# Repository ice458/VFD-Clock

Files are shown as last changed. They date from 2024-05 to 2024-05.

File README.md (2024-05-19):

# VFD-Clock
This is a project for a table clock using a VFD.  
For more information, please visit [this site.](https://ice458.wordpress.com/%e5%ae%9f%e7%94%a8%e7%9a%84%e3%81%aavfd%e6%99%82%e8%a8%88/)  
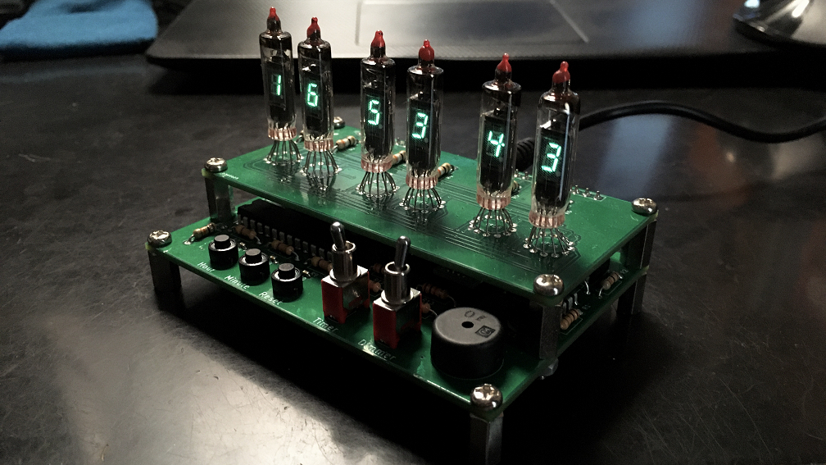
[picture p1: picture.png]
  

## License

The files contained in [VFD2.X/mcc_generated_files](VFD2.X/mcc_generated_files) are copyrighted by Microchip. The code can only be used in Microchip products. Please refer to the comments at the top of the files for details.

Other files are subject to the overall license [LICENSE](LICENSE).

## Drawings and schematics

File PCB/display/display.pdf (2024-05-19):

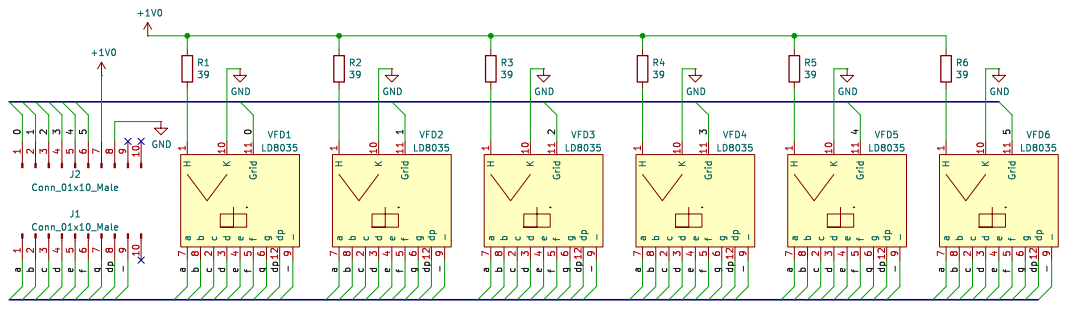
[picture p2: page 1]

Id: 1/1 Title: File: display.kicad_sch Sheet: /

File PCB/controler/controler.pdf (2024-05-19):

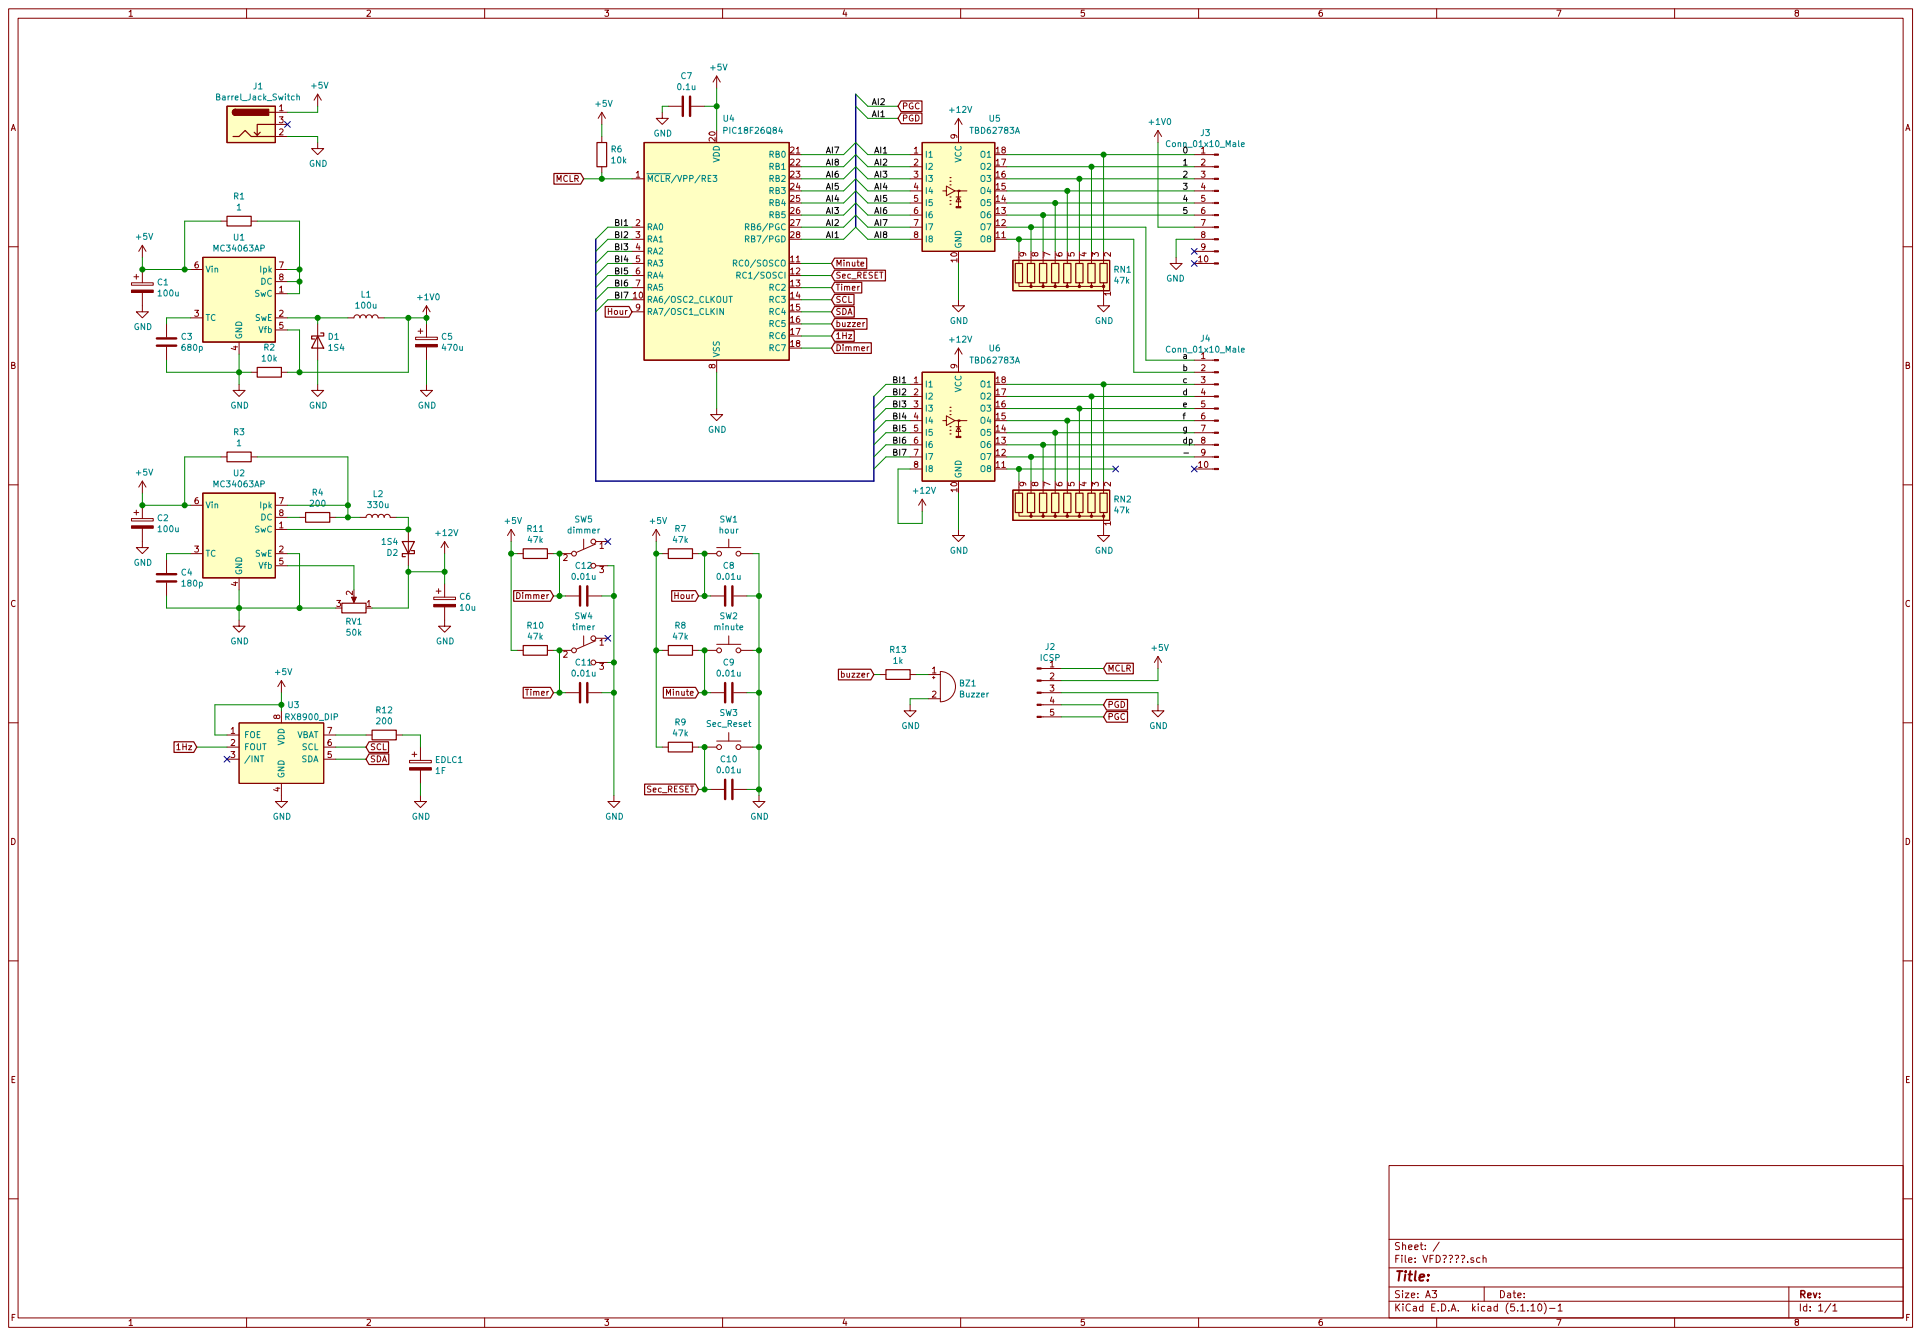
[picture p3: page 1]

9 U6 TBD62783A MCLR/VPP/RE3 1 RA6/OSC2_CLKOUT 10 RC0/SOSCO 11 RC1/SOSCI 12 RC2 13 RC3 14 RC4 15 RC5 16 RC6 17 RC7 18 RA0 2 VDD 20 RB0 21 RB1 22 RB2 23 RB3 24 RB4 25 RB5 26 RB6/PGC 27 RB7/PGD 28 RA1 3 RA2 4 RA3 5 RA4 6 RA5 7 VSS

4 SDA 5 SCL 6 VBAT 7 VDD

Id: 1/1 Title: File: VFD.sch Sheet: /

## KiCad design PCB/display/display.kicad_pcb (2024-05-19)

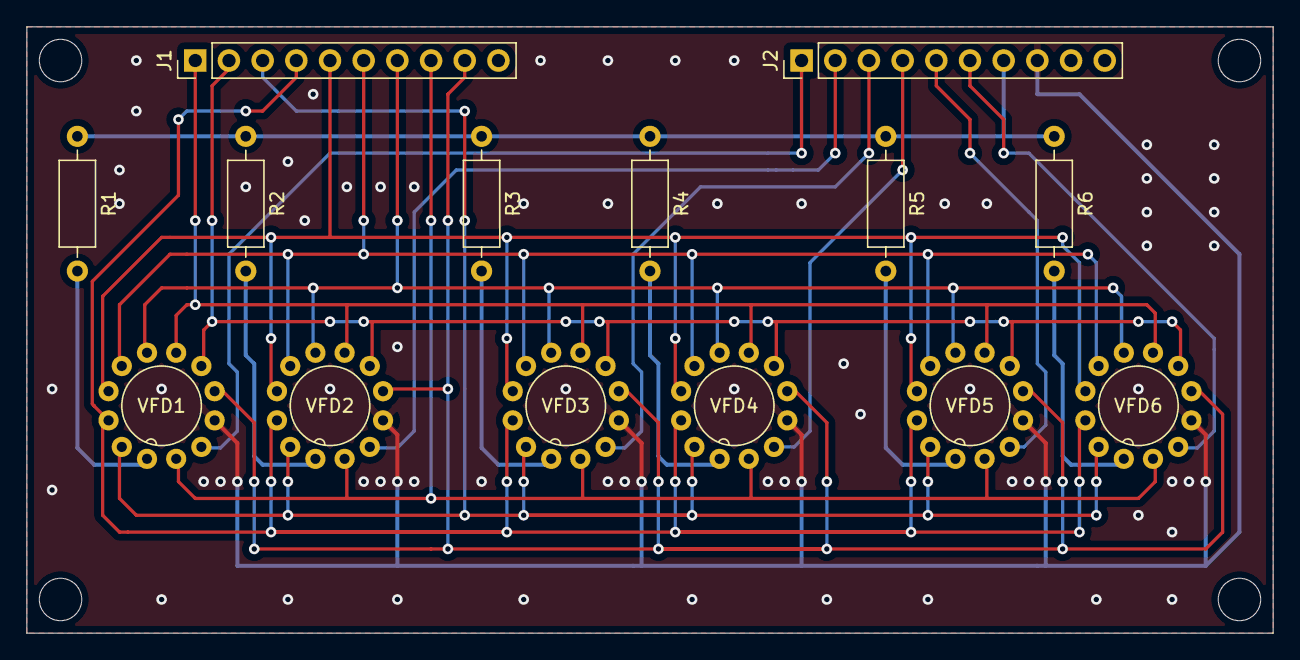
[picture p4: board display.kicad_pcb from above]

Board: 2 copper layers, 94.0 x 45.7 mm, 14 parts (0 on the bottom side), 23 nets.

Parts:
J1, J2: Conn_01x10_Male; PinHeader_1x10_P2.54mm_Vertical
R1, R2, R3, R4, R5, R6: R; R_Axial_DIN0207_L6.3mm_D2.5mm_P10.16mm_Horizontal
VFD1, VFD2, VFD3, VFD4, VFD5, VFD6: LD8035

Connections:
+1V0: J2.7, R1.1, R2.1, R3.1, R4.1, R5.1, R6.1
/0: J2.1, VFD1.11
/1: J2.2, VFD2.11
/2: J2.3, VFD3.11
/3: J2.4, VFD4.11
/4: J2.5, VFD5.11
/5: J2.6, VFD6.11
/-: J1.9, VFD1.9, VFD2.9, VFD3.9, VFD4.9, VFD5.9, VFD6.9
/a: J1.1, VFD1.7, VFD2.7, VFD3.7, VFD4.7, VFD5.7, VFD6.7
/b: J1.2, VFD1.8, VFD2.8, VFD3.8, VFD4.8, VFD5.8, VFD6.8
/c: J1.3, VFD1.2, VFD2.2, VFD3.2, VFD4.2, VFD5.2, VFD6.2
/d: J1.4, VFD1.3, VFD2.3, VFD3.3, VFD4.3, VFD5.3, VFD6.3
/dp: J1.8, VFD1.12, VFD2.12, VFD3.12, VFD4.12, VFD5.12, VFD6.12
/e: J1.5, VFD1.4, VFD2.4, VFD3.4, VFD4.4, VFD5.4, VFD6.4
/f: J1.6, VFD1.5, VFD2.5, VFD3.5, VFD4.5, VFD5.5, VFD6.5
/g: J1.7, VFD1.6, VFD2.6, VFD3.6, VFD4.6, VFD5.6, VFD6.6
GND: J2.8, VFD1.10, VFD2.10, VFD3.10, VFD4.10, VFD5.10, VFD6.10
unnamed: R1.2, VFD1.1
unnamed: R2.2, VFD2.1
unnamed: R3.2, VFD3.1
unnamed: R4.2, VFD4.1
unnamed: R5.2, VFD5.1
unnamed: R6.2, VFD6.1

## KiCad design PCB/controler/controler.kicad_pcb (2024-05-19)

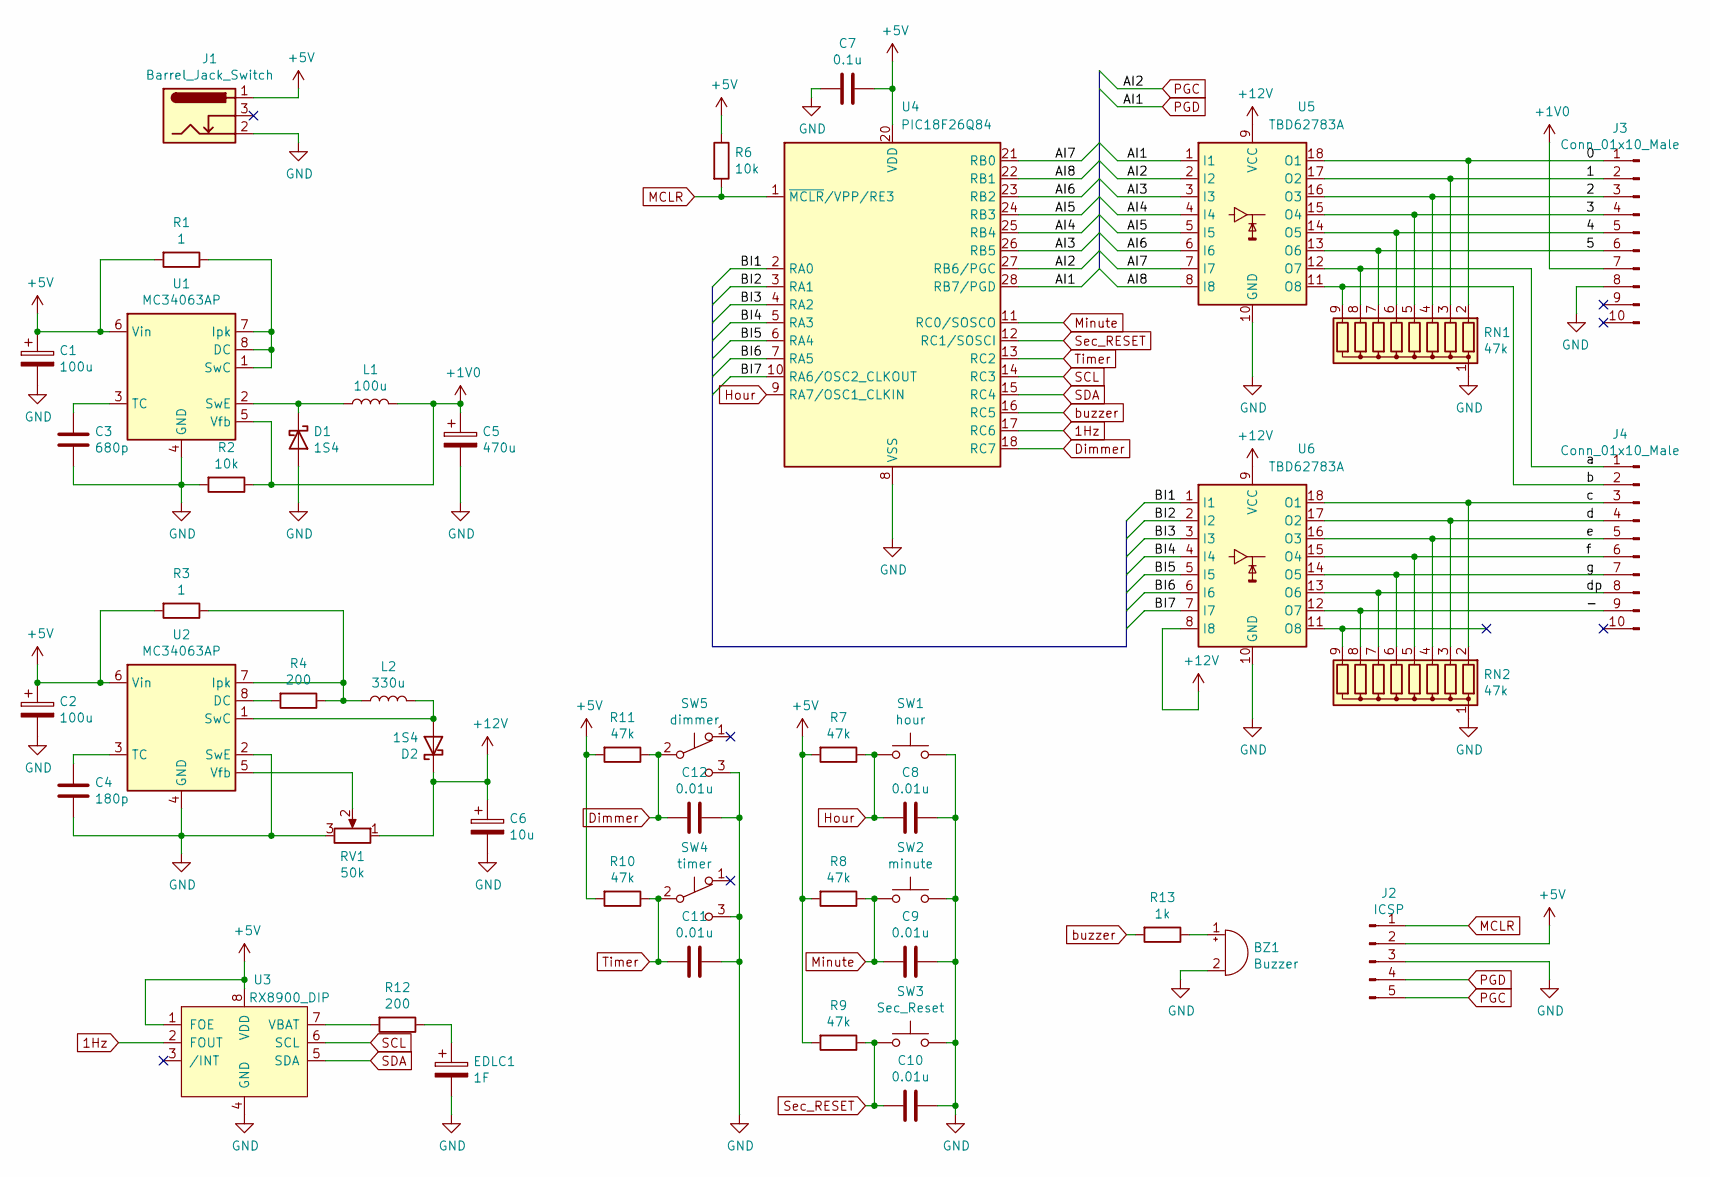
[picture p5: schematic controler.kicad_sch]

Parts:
BZ1: Buzzer; Buzzer_TDK_PS1240P02BT_D12.2mm_H6.5mm
C1, C2: 100u; CP_Radial_D6.3mm_P2.50mm
C3: 680p; C_Disc_D3.0mm_W1.6mm_P2.50mm
C4: 180p; C_Disc_D3.0mm_W1.6mm_P2.50mm
C5: 470u; CP_EIA-7343-30_AVX-N_Pad2.25x2.55mm_HandSolder
C6: 10u; CP_Radial_D5.0mm_P2.00mm
C7: 0.1u; C_0603_1608Metric_Pad1.08x0.95mm_HandSolder
C8, C9, C10, C11, C12: 0.01u; C_0603_1608Metric_Pad1.08x0.95mm_HandSolder
D1, D2: 1S4; D_DO-34_SOD68_P2.54mm_Vertical_AnodeUp
EDLC1: 1F; EDLC
J1: Barrel_Jack_Switch; BarrelJack_CUI_PJ-102AH_Horizontal
J2: ICSP; PinHeader_1x05_P2.54mm_Vertical
J3, J4: Conn_01x10_Male; PinHeader_1x10_P2.54mm_Vertical
L1: 100u; L_Axial_L9.5mm_D4.0mm_P12.70mm_Horizontal_Fastron_SMCC
L2: 330u; L_Axial_L9.5mm_D4.0mm_P12.70mm_Horizontal_Fastron_SMCC
R1, R3: 1; R_Axial_DIN0207_L6.3mm_D2.5mm_P10.16mm_Horizontal
R2, R6: 10k; R_Axial_DIN0207_L6.3mm_D2.5mm_P10.16mm_Horizontal
R4, R12: 200; R_Axial_DIN0207_L6.3mm_D2.5mm_P10.16mm_Horizontal
R7, R8, R9, R10, R11: 47k; R_Axial_DIN0207_L6.3mm_D2.5mm_P10.16mm_Horizontal
R13: 1k; R_Axial_DIN0207_L6.3mm_D2.5mm_P10.16mm_Horizontal
RN1, RN2: 47k; R_Array_SIP9
RV1: 50k; Potentiometer_Bourns_3386C_Horizontal
SW1: hour; R_Axial_DIN0204_L3.6mm_D1.6mm_P5.08mm_Horizontal
SW2: minute; R_Axial_DIN0204_L3.6mm_D1.6mm_P5.08mm_Horizontal
SW3: Sec_Reset; R_Axial_DIN0204_L3.6mm_D1.6mm_P5.08mm_Horizontal
SW4: timer; PinHeader_1x03_P2.54mm_Vertical
SW5: dimmer; PinHeader_1x03_P2.54mm_Vertical
U1, U2: MC34063AP; DIP-8_W7.62mm
U3: RX8900_DIP; DIP-8_Module_W7.62mm
U4: PIC18F26Q84; DIP-28_W7.62mm
U5, U6: TBD62783A; DIP-18_W7.62mm

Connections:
1Hz: U3.2 (FOUT), U4.17 (RC6)
+1V0: C5.1, J3.7, L1.2, R2.1, U1.5 (Vfb)
+5V: C1.1, C2.1, C7.1, J1.1, J2.2, R1.2, R3.2, R6.1, R7.2, R8.2, R9.2, R10.2, R11.2, U1.6 (Vin), U2.6 (Vin), U3.1 (FOE), U3.8 (VDD), U4.20 (VDD)
+12V: C6.1, D2.1 (K), RV1.1, U5.9 (VCC), U6.8 (I8), U6.9 (VCC)
/0: J3.1, RN1.2 (R1), U5.18 (O1)
/1: J3.2, RN1.3 (R2), U5.17 (O2)
/2: J3.3, RN1.4 (R3), U5.16 (O3)
/3: J3.4, RN1.5 (R4), U5.15 (O4)
/4: J3.5, RN1.6 (R5), U5.14 (O5)
/5: J3.6, RN1.7 (R6), U5.13 (O6)
/-: J4.9, RN2.8 (R7), U6.12 (O7)
/AI3: U4.26 (RB5), U5.3 (I3)
/AI4: U4.25 (RB4), U5.4 (I4)
/AI5: U4.24 (RB3), U5.5 (I5)
/AI6: U4.23 (RB2), U5.6 (I6)
/AI7: U4.21 (RB0), U5.7 (I7)
/AI8: U4.22 (RB1), U5.8 (I8)
/BI1: U4.2 (RA0), U6.1 (I1)
/BI2: U4.3 (RA1), U6.2 (I2)
/BI3: U4.4 (RA2), U6.3 (I3)
/BI4: U4.5 (RA3), U6.4 (I4)
/BI5: U4.6 (RA4), U6.5 (I5)
/BI6: U4.7 (RA5), U6.6 (I6)
/BI7: U4.10 (RA6/OSC2_CLKOUT), U6.7 (I7)
/a: J4.1, RN1.8 (R7), U5.12 (O7)
/b: J4.2, RN1.9 (R8), U5.11 (O8)
/c: J4.3, RN2.2 (R1), U6.18 (O1)
/d: J4.4, RN2.3 (R2), U6.17 (O2)
/dp: J4.8, RN2.7 (R6), U6.13 (O6)
/e: J4.5, RN2.4 (R3), U6.16 (O3)
/f: J4.6, RN2.5 (R4), U6.15 (O4)
/g: J4.7, RN2.6 (R5), U6.14 (O5)
Dimmer: C12.2, R11.1, SW5.2 (B), U4.18 (RC7)
GND: BZ1.2 (+), C1.2, C2.2, C3.2, C4.2, C5.2, C6.2, C7.2, C8.1, C9.1, C10.1, C11.1, C12.1, D1.2 (A), EDLC1.2, J1.2, J2.3, J3.8, R2.2, RN1.1 (common), RN2.1 (common), RV1.3, SW1.2, SW2.2, SW3.2, SW4.3 (C), SW5.3 (C), U1.4 (GND), U2.2 (SwE), U2.4 (GND), U3.4 (GND), U4.8 (VSS), U4.19 (VSS), U5.10 (GND), U6.10 (GND)
Hour: C8.2, R7.1, SW1.1, U4.9 (RA7/OSC1_CLKIN)
MCLR: J2.1, R6.2, U4.1 (~MCLR/VPP/RE3)
Minute: C9.2, R8.1, SW2.1, U4.11 (RC0/SOSCO)
unnamed: BZ1.1 (-), R13.1
unnamed: C3.1, U1.3 (TC)
unnamed: C4.1, U2.3 (TC)
unnamed: D1.1 (K), L1.1, U1.2 (SwE)
unnamed: D2.2 (A), L2.2, U2.1 (SwC)
unnamed: EDLC1.1, R12.1
unnamed: L2.1, R3.1, R4.1, U2.7 (Ipk)
unnamed: R1.1, U1.1 (SwC), U1.7 (Ipk), U1.8 (DC)
unnamed: R4.2, U2.8 (DC)
unnamed: R12.2, U3.7 (VBAT)
unnamed: RN2.9 (R8), U6.11 (O8)
unnamed: RV1.2, U2.5 (Vfb)
PGC: J2.5, U4.27 (RB6/PGC), U5.2 (I2)
PGD: J2.4, U4.28 (RB7/PGD), U5.1 (I1)
SCL: U3.6 (SCL), U4.14 (RC3)
SDA: U3.5 (SDA), U4.15 (RC4)
Sec_RESET: C10.2, R9.1, SW3.1, U4.12 (RC1/SOSCI)
Timer: C11.2, R10.1, SW4.2 (B), U4.13 (RC2)
buzzer: R13.2, U4.16 (RC5)

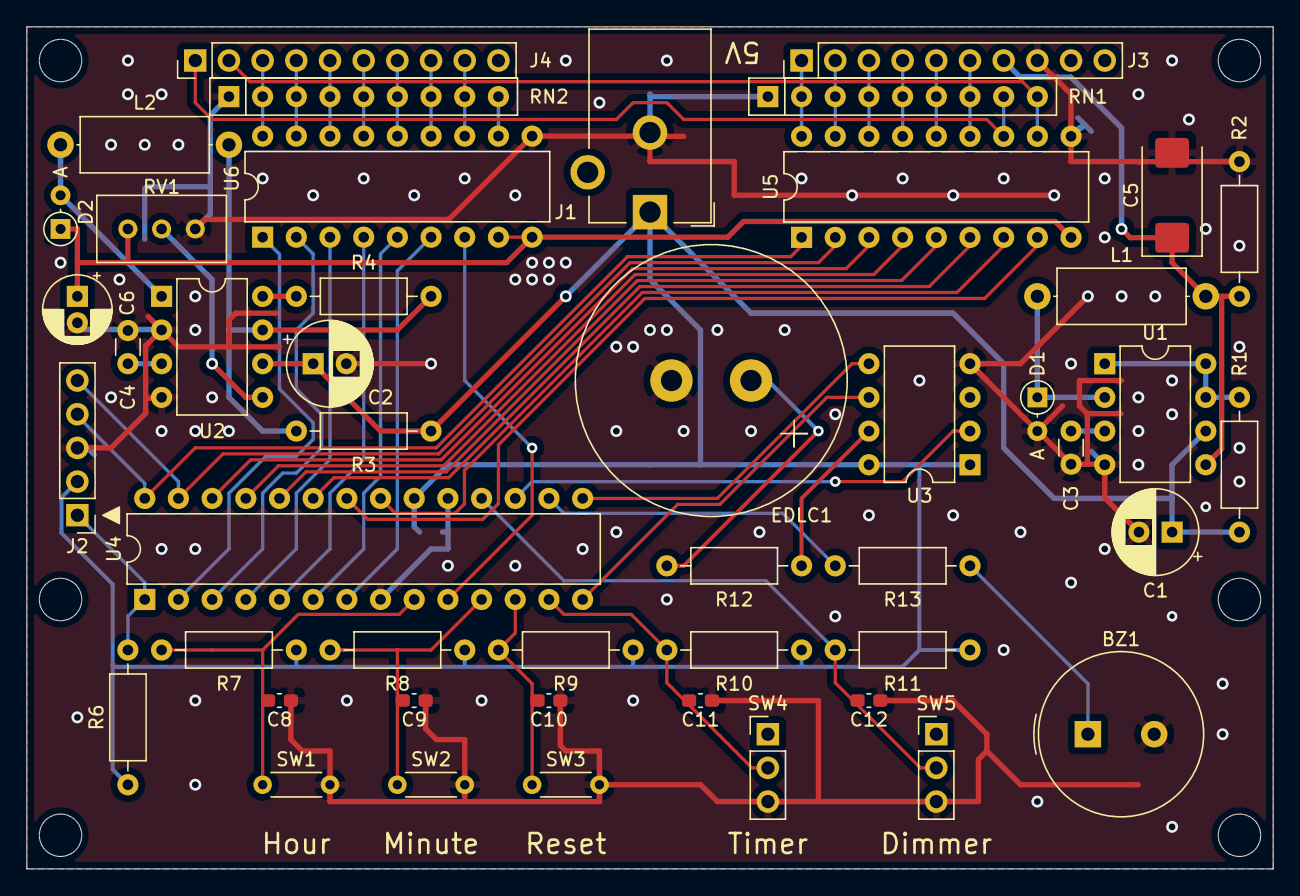
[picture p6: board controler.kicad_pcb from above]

Board: 2 copper layers, 94.0 x 63.5 mm, 48 parts (1 on the bottom side), 56 nets.

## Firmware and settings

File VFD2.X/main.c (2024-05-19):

#include "mcc_generated_files/mcc.h"
#include "dinamic.h"
#include "RX8900.h"

// VFD表示更新フラグ
bool FLAG_NEW = false;
// ボタン立ち下がり検出フラグ
bool FLAG_BTN = false;
// アラーム時間表示フラグ
bool FLAG_SHOW_ALARM = false;

// VFD表示更新
void time_new()
{
    FLAG_NEW = true;
}

// アラーム設定時の表示時間カウント(500ms/1カウント)
void show_counter()
{
    static uint8_t count = 0;
    if(count == 7)
    {
        FLAG_SHOW_ALARM = false;
        TMR1_StopTimer();
        count = 0;
    }
    else
    {
        count++;
    }
}

// アラーム
void alarm(bool set)
{
    NCO1CONbits.EN = set;
    NCO2CONbits.EN = set;
    NCO3CONbits.EN = set;
}



void main(void)
{
    SYSTEM_Initialize();

    PIE0bits.IOCIE = 0; 
    INTERRUPT_GlobalInterruptHighEnable();
    INTERRUPT_GlobalInterruptLowEnable();
    
    __delay_ms(30);
    
    // WWDT
    WWDT_SoftEnable();
    
    // 初期化
    Init_RX8900();
    Init_VFD();
    
    IOCCF6_SetInterruptHandler(time_new);
    TMR1_SetInterruptHandler(show_counter);
    
    PIE0bits.IOCIE = 1; 
    
    // vfd表示バッファ
    uint8_t d[6] = {8,8,8,8,8,8};
    // 全点灯
    Set_VFD(d, 0b111111);
    
    // ピリオド表示位置
    uint8_t period = 0b000000;
    // 時間
    bcdtime_t time = ReadBCDTime_RX8900();
    // timeのコピー。時刻設定用
    bcdtime_t wr_time_buf = time;
    // アラーム時刻
    bcdtime_t alarm_time = ReadBCDAlarmTime_RX8900();
    
    // timer_swのエッジ検出用
    bool last_timer_sw_state = false;
    bool now_timer_sw_state = !SW_Timer_PORT;
    
    while (1)
    {
        // VFD表示
        if(FLAG_NEW)
        {
            // アラーム時刻表示
            if(FLAG_SHOW_ALARM)
            {
                period = RTC_1Hz_PORT ? 0b001010 : 0;
                d[5] = DINAMIC_COL_OFF;
                d[4] = DINAMIC_COL_OFF;
                d[3] = alarm_time.min & 0x0F;
                d[2] = (alarm_time.min & 0xF0) >> 4;
                d[1] = alarm_time.hour & 0x0F;
                d[0] = (alarm_time.hour & 0xF0) >> 4;
            }
            // 時刻表示
            else
            {
                time = ReadBCDTime_RX8900();
                wr_time_buf = time;
                period = 0b000000;
                
                d[5] = time.sec & 0x0F;
                d[4] = (time.sec & 0xF0) >> 4;
                d[3] = time.min & 0x0F;
                d[2] = (time.min & 0xF0) >> 4;
                d[1] = time.hour & 0x0F;
                d[0] = (time.hour & 0xF0) >> 4;
            }
            
            Set_VFD(d, period);
            FLAG_NEW = false;
        }
        
        // timer_swのエッジ検出用
        now_timer_sw_state = !SW_Timer_PORT;
        
        // timer_swがオンの時の処理
        if(now_timer_sw_state == true)
        {
            // timer_sw立ち上がり
            if(last_timer_sw_state == false)
            {
                TMR1_StartTimer();
                TMR1_WriteTimer(0);
                FLAG_NEW = true;
                FLAG_SHOW_ALARM = true; 
            }
            
            // アラーム
            if(alarm_time.hour == time.hour && alarm_time.min == time.min &&
                                alarm_time.sec == time.sec && !FLAG_SHOW_ALARM)
            {
                alarm(true);
            }
            
            // アラーム設定
            if(BTN_Reset_PORT == 0 && FLAG_BTN == 0)
            {
                TMR1_StartTimer();
                TMR1_WriteTimer(0);
                FLAG_NEW = true;
                FLAG_BTN = true;
                FLAG_SHOW_ALARM = true;
            }
            else if(BTN_Minute_PORT == 0 && FLAG_BTN == 0)
            {
                uint8_t chage_buf;
                
                TMR1_StartTimer();
                TMR1_WriteTimer(0);
                FLAG_NEW = true;
                FLAG_BTN = true;
                FLAG_SHOW_ALARM = true;
                
                chage_buf = Change_BCD_to_BIN(alarm_time.min);
                if(chage_buf >= 59) chage_buf = 0;
                else chage_buf++;
                alarm_time.min = Change_BIN_to_BCD(chage_buf);
                WriteBCDAlarmTime_RX8900(alarm_time);
            }
            else if(BTN_Hour_PORT == 0 && FLAG_BTN == 0)
            {
                uint8_t chage_buf;
                
                TMR1_StartTimer();
                TMR1_WriteTimer(0);
                FLAG_NEW = true;
                FLAG_BTN = true;
                FLAG_SHOW_ALARM = true;
                
                chage_buf = Change_BCD_to_BIN(alarm_time.hour);
                if(chage_buf >= 23) chage_buf = 0;
                else chage_buf++;
                alarm_time.hour = Change_BIN_to_BCD(chage_buf);
                WriteBCDAlarmTime_RX8900(alarm_time);
            }

            if(BTN_Reset_PORT && BTN_Minute_PORT && BTN_Hour_PORT)
                FLAG_BTN = false;
        }
        
        // timer_swがオフの時の処理
        else
        {
            // アラーム解除
            if(last_timer_sw_state == true)
            {
                alarm(false);
            }
            
            // 時刻設定
            if(BTN_Reset_PORT == 0 && FLAG_BTN == 0)
            {
                FLAG_NEW = true;
                FLAG_BTN = true;
                wr_time_buf.sec = 0;
                WriteBCDTime_RX8900(wr_time_buf);
            }
            else if(BTN_Minute_PORT == 0 && FLAG_BTN == 0)
            {
                FLAG_NEW = true;
                FLAG_BTN = true;
                uint8_t chage_buf;
                chage_buf = Change_BCD_to_BIN(wr_time_buf.min);
                if(chage_buf >= 59) chage_buf = 0;
                else chage_buf++;
                wr_time_buf.min = Change_BIN_to_BCD(chage_buf);
                WriteBCDTime_RX8900(wr_time_buf);
            }
            else if(BTN_Hour_PORT == 0 && FLAG_BTN == 0)
            {
                FLAG_NEW = true;
                FLAG_BTN = true;
                uint8_t chage_buf;
                chage_buf = Change_BCD_to_BIN(wr_time_buf.hour);
                if(chage_buf >= 23) chage_buf = 0;
                else chage_buf++;
                wr_time_buf.hour = Change_BIN_to_BCD(chage_buf);
                WriteBCDTime_RX8900(wr_time_buf);
            }

            if(BTN_Reset_PORT && BTN_Minute_PORT && BTN_Hour_PORT)
                FLAG_BTN = false;
        }
        
        // 明るさ設定
        if(!SW_Dimmer_PORT && (time.hour <= Change_BIN_to_BCD(4)))
        {
            Set_Dimmer(4);
        }
        else if(!SW_Dimmer_PORT && (Change_BIN_to_BCD(22) <= time.hour ||
                                time.hour <= Change_BIN_to_BCD(5)))
        {
            Set_Dimmer(2);
        }
        else if(!SW_Dimmer_PORT && (Change_BIN_to_BCD(20) <= time.hour ||
                                time.hour <= Change_BIN_to_BCD(6)))
        {
            Set_Dimmer(1);
        }
        else
        {
            Set_Dimmer(0);
        }
        
        // timer_swのエッジ検出用
        last_timer_sw_state = now_timer_sw_state;
        
        WWDT_TimerClear();
    }
}

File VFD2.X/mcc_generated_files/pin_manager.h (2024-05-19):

/**
  @Generated Pin Manager Header File

  @Company:
    Microchip Technology Inc.

  @File Name:
    pin_manager.h

  @Summary:
    This is the Pin Manager file generated using PIC10 / PIC12 / PIC16 / PIC18 MCUs

  @Description
    This header file provides APIs for driver for .
    Generation Information :
        Product Revision  :  PIC10 / PIC12 / PIC16 / PIC18 MCUs - 1.81.7
        Device            :  PIC18F26Q84
        Driver Version    :  2.11
    The generated drivers are tested against the following:
        Compiler          :  XC8 2.31 and above
        MPLAB 	          :  MPLAB X 5.45	
*/

/*
    (c) 2018 Microchip Technology Inc. and its subsidiaries. 
    
    Subject to your compliance with these terms, you may use Microchip software and any 
    derivatives exclusively with Microchip products. It is your responsibility to comply with third party 
    license terms applicable to your use of third party software (including open source software) that 
    may accompany Microchip software.
    
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
    IN NO EVENT WILL MICROCHIP BE LIABLE FOR ANY INDIRECT, SPECIAL, PUNITIVE, 
    INCIDENTAL OR CONSEQUENTIAL LOSS, DAMAGE, COST OR EXPENSE OF ANY KIND 
    WHATSOEVER RELATED TO THE SOFTWARE, HOWEVER CAUSED, EVEN IF MICROCHIP 
    HAS BEEN ADVISED OF THE POSSIBILITY OR THE DAMAGES ARE FORESEEABLE. TO 
    THE FULLEST EXTENT ALLOWED BY LAW, MICROCHIP'S TOTAL LIABILITY ON ALL 
    CLAIMS IN ANY WAY RELATED TO THIS SOFTWARE WILL NOT EXCEED THE AMOUNT 
    OF FEES, IF ANY, THAT YOU HAVE PAID DIRECTLY TO MICROCHIP FOR THIS 
    SOFTWARE.
*/

#ifndef PIN_MANAGER_H
#define PIN_MANAGER_H

/**
  Section: Included Files
*/

#include <xc.h>

#define INPUT   1
#define OUTPUT  0

#define HIGH    1
#define LOW     0

#define ANALOG      1
#define DIGITAL     0

#define PULL_UP_ENABLED      1
#define PULL_UP_DISABLED     0

// get/set Seg_C aliases
#define Seg_C_TRIS                 TRISAbits.TRISA0
#define Seg_C_LAT                  LATAbits.LATA0
#define Seg_C_PORT                 PORTAbits.RA0
#define Seg_C_WPU                  WPUAbits.WPUA0
#define Seg_C_OD                   ODCONAbits.ODCA0
#define Seg_C_ANS                  ANSELAbits.ANSELA0
#define Seg_C_SetHigh()            do { LATAbits.LATA0 = 1; } while(0)
#define Seg_C_SetLow()             do { LATAbits.LATA0 = 0; } while(0)
#define Seg_C_Toggle()             do { LATAbits.LATA0 = ~LATAbits.LATA0; } while(0)
#define Seg_C_GetValue()           PORTAbits.RA0
#define Seg_C_SetDigitalInput()    do { TRISAbits.TRISA0 = 1; } while(0)
#define Seg_C_SetDigitalOutput()   do { TRISAbits.TRISA0 = 0; } while(0)
#define Seg_C_SetPullup()          do { WPUAbits.WPUA0 = 1; } while(0)
#define Seg_C_ResetPullup()        do { WPUAbits.WPUA0 = 0; } while(0)
#define Seg_C_SetPushPull()        do { ODCONAbits.ODCA0 = 0; } while(0)
#define Seg_C_SetOpenDrain()       do { ODCONAbits.ODCA0 = 1; } while(0)
#define Seg_C_SetAnalogMode()      do { ANSELAbits.ANSELA0 = 1; } while(0)
#define Seg_C_SetDigitalMode()     do { ANSELAbits.ANSELA0 = 0; } while(0)

// get/set Seg_D aliases
#define Seg_D_TRIS                 TRISAbits.TRISA1
#define Seg_D_LAT                  LATAbits.LATA1
#define Seg_D_PORT                 PORTAbits.RA1
#define Seg_D_WPU                  WPUAbits.WPUA1
#define Seg_D_OD                   ODCONAbits.ODCA1
#define Seg_D_ANS                  ANSELAbits.ANSELA1
#define Seg_D_SetHigh()            do { LATAbits.LATA1 = 1; } while(0)
#define Seg_D_SetLow()             do { LATAbits.LATA1 = 0; } while(0)
#define Seg_D_Toggle()             do { LATAbits.LATA1 = ~LATAbits.LATA1; } while(0)
#define Seg_D_GetValue()           PORTAbits.RA1
#define Seg_D_SetDigitalInput()    do { TRISAbits.TRISA1 = 1; } while(0)
#define Seg_D_SetDigitalOutput()   do { TRISAbits.TRISA1 = 0; } while(0)
#define Seg_D_SetPullup()          do { WPUAbits.WPUA1 = 1; } while(0)
#define Seg_D_ResetPullup()        do { WPUAbits.WPUA1 = 0; } while(0)
#define Seg_D_SetPushPull()        do { ODCONAbits.ODCA1 = 0; } while(0)
#define Seg_D_SetOpenDrain()       do { ODCONAbits.ODCA1 = 1; } while(0)
#define Seg_D_SetAnalogMode()      do { ANSELAbits.ANSELA1 = 1; } while(0)
#define Seg_D_SetDigitalMode()     do { ANSELAbits.ANSELA1 = 0; } while(0)

// get/set Seg_E aliases
#define Seg_E_TRIS                 TRISAbits.TRISA2
#define Seg_E_LAT                  LATAbits.LATA2
#define Seg_E_PORT                 PORTAbits.RA2
#define Seg_E_WPU                  WPUAbits.WPUA2
#define Seg_E_OD                   ODCONAbits.ODCA2
#define Seg_E_ANS                  ANSELAbits.ANSELA2
#define Seg_E_SetHigh()            do { LATAbits.LATA2 = 1; } while(0)
#define Seg_E_SetLow()             do { LATAbits.LATA2 = 0; } while(0)
#define Seg_E_Toggle()             do { LATAbits.LATA2 = ~LATAbits.LATA2; } while(0)
#define Seg_E_GetValue()           PORTAbits.RA2
#define Seg_E_SetDigitalInput()    do { TRISAbits.TRISA2 = 1; } while(0)
#define Seg_E_SetDigitalOutput()   do { TRISAbits.TRISA2 = 0; } while(0)
#define Seg_E_SetPullup()          do { WPUAbits.WPUA2 = 1; } while(0)
#define Seg_E_ResetPullup()        do { WPUAbits.WPUA2 = 0; } while(0)
#define Seg_E_SetPushPull()        do { ODCONAbits.ODCA2 = 0; } while(0)
#define Seg_E_SetOpenDrain()       do { ODCONAbits.ODCA2 = 1; } while(0)
#define Seg_E_SetAnalogMode()      do { ANSELAbits.ANSELA2 = 1; } while(0)
#define Seg_E_SetDigitalMode()     do { ANSELAbits.ANSELA2 = 0; } while(0)

// get/set Seg_F aliases
#define Seg_F_TRIS                 TRISAbits.TRISA3
#define Seg_F_LAT                  LATAbits.LATA3
#define Seg_F_PORT                 PORTAbits.RA3
#define Seg_F_WPU                  WPUAbits.WPUA3
#define Seg_F_OD                   ODCONAbits.ODCA3
#define Seg_F_ANS                  ANSELAbits.ANSELA3
#define Seg_F_SetHigh()            do { LATAbits.LATA3 = 1; } while(0)
#define Seg_F_SetLow()             do { LATAbits.LATA3 = 0; } while(0)
#define Seg_F_Toggle()             do { LATAbits.LATA3 = ~LATAbits.LATA3; } while(0)
#define Seg_F_GetValue()           PORTAbits.RA3
#define Seg_F_SetDigitalInput()    do { TRISAbits.TRISA3 = 1; } while(0)
#define Seg_F_SetDigitalOutput()   do { TRISAbits.TRISA3 = 0; } while(0)
#define Seg_F_SetPullup()          do { WPUAbits.WPUA3 = 1; } while(0)
#define Seg_F_ResetPullup()        do { WPUAbits.WPUA3 = 0; } while(0)
#define Seg_F_SetPushPull()        do { ODCONAbits.ODCA3 = 0; } while(0)
#define Seg_F_SetOpenDrain()       do { ODCONAbits.ODCA3 = 1; } while(0)
#define Seg_F_SetAnalogMode()      do { ANSELAbits.ANSELA3 = 1; } while(0)
#define Seg_F_SetDigitalMode()     do { ANSELAbits.ANSELA3 = 0; } while(0)
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
